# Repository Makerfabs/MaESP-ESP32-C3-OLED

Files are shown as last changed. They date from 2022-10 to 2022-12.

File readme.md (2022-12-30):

# MaESP ESP32 C3 OLED

```c++
/*
Version:		V1.2
Author:			Vincent
Create Date:	2022/9/23
Note:
	2022/12/30	V1.2: Change wiki link
	2022/10/26	V1.1: Add product link and wiki link
*/
```
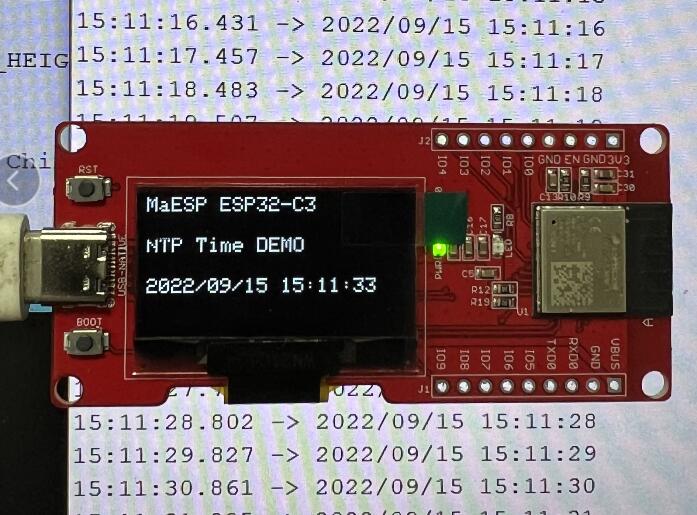
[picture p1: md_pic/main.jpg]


[toc]

# Makerfabs

[Makerfabs home page](https://www.makerfabs.com/)

[Makerfabs Wiki](https://wiki.makerfabs.com/)

# MaESP ESP32 C3 OLED
## Intruduce

Product Link ： [MaESP ESP32-C3 Board with 1.3" OLED](https://www.makerfabs.com/maesp-esp32-c3-board-with-1-3-oled.html)

Wiki Link : [MaESP ESP32-C3 OLED](https://wiki.makerfabs.com/MaESP_ESP32_C3_OLED.html)

MaESP ESP32 C3 OLED equips with ESP32-C3, which is a single-core Wi-Fi and Bluetooth 5 (LE) microcontroller SoC, built around a 32-bit **RISC-V** chip processor with a four-stage pipeline that operates at up to 160 MHz, with 4MB Flash, 400KB SRAM. 

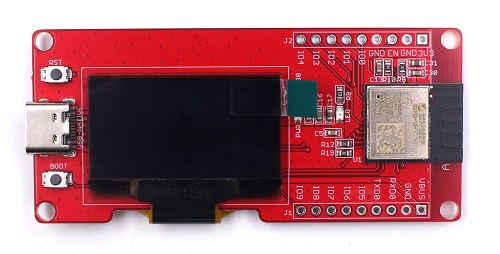
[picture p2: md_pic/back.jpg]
back


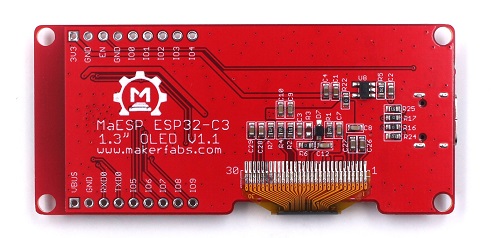
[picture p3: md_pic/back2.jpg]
back2


## Feature

- Controller: ESP32-C3-MINI-1-N4, 4MB Flash, RISCV-32bit, 160MHz, 400KB SRAM, Bluetooth 5
- Wireless: WiFi & Bluetooth 5.0
- Power Supply: USB Type-C 5.0V(4.0V~5.25V)
- Button: Flash button and reset button
- Arduino support: Yes
- Operation temperature: -40℃ to +85℃

# Code

## Complier Option

- Install board : ESP32 .
- Install library : Adafruit_SSD1306, Adafruit_GFX libraries. 
- Use type-c use cable connect USBto PC.
- Upload codes, select "ESP32-C3 DEV Module"
- Some times need press boot button and reset, when COM port not appear.

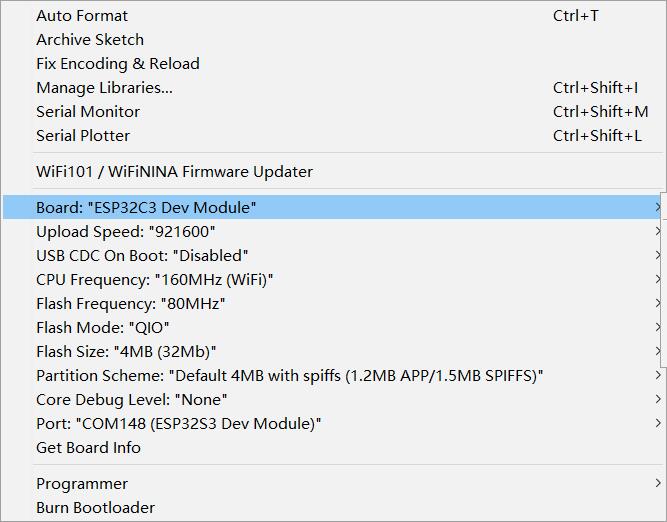
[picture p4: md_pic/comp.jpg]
comp


## Firmware

### CDC_OLED

Different from the commonly used Arduino, the USB interface is directly connected to the ESP32C3, without CP2104 and other chips.

 Therefore, to enable the serial port to send logs normally, use the USBSerial object. This demo show how to use USBSerial and show logo on OLED.

## Example

### NTP_Time

Need chang wifi config .

```c++
#define SSID "Makerfabs"
#define PWD "20160704"
```

Will display NTP time to OLED.

### DHT11_ThingSpeak

Need change ThingSpeak upload url to yourself.

```c++
    String url = "http://api.thingspeak.com/update?api_key=KCAT79TTH52MG7EA&field1=";
    url = url + t + "&field2=" + h;
```

It sends the current temperature and humidity to ThingSpeak when it starts up, and periodically displays the latest temperature and humidity to the OLED.

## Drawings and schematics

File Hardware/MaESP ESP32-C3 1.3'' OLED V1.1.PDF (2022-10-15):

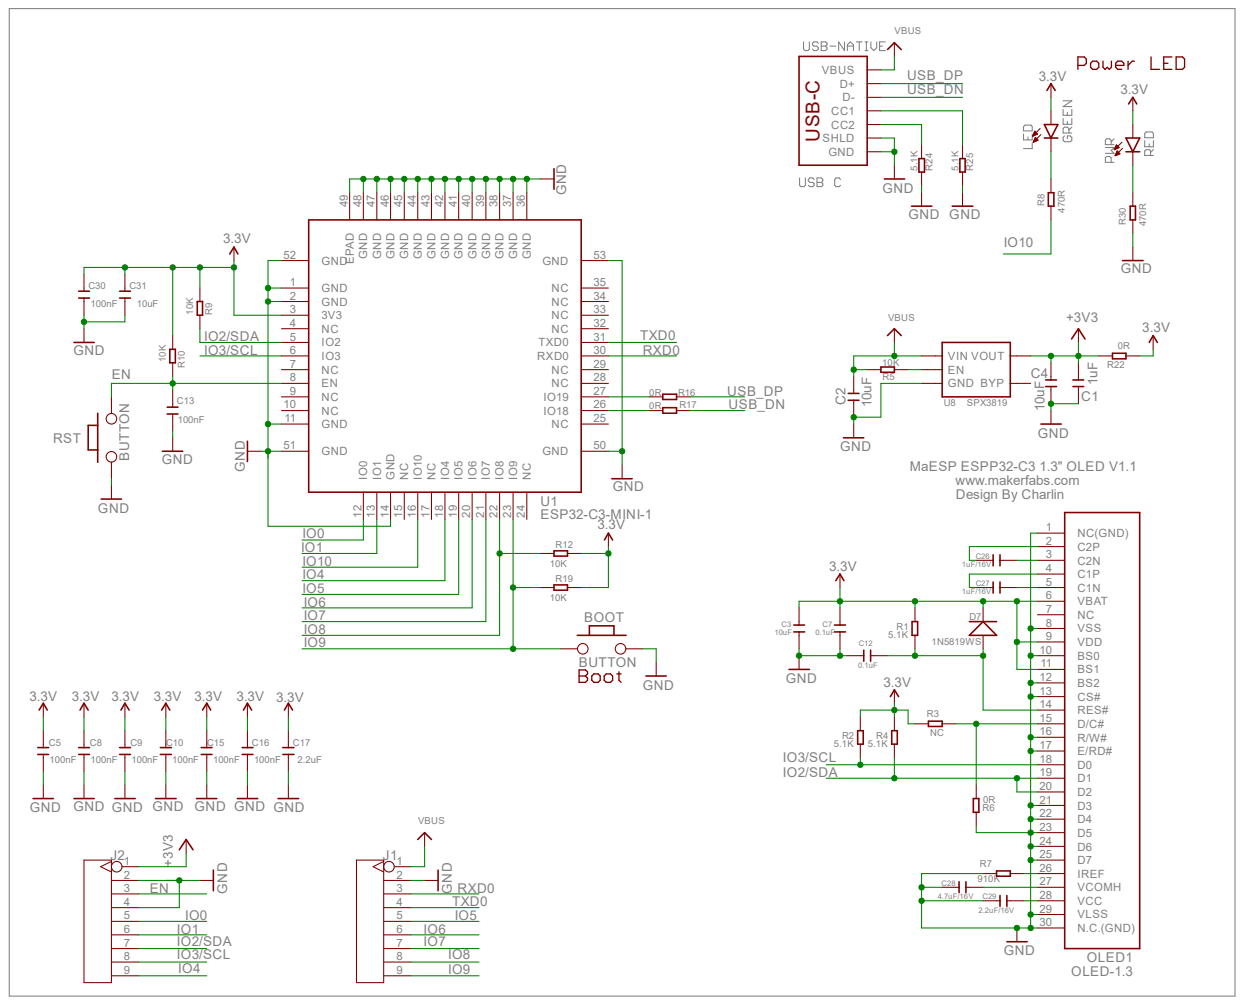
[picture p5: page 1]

NC 7 VSS 8 VDD 9

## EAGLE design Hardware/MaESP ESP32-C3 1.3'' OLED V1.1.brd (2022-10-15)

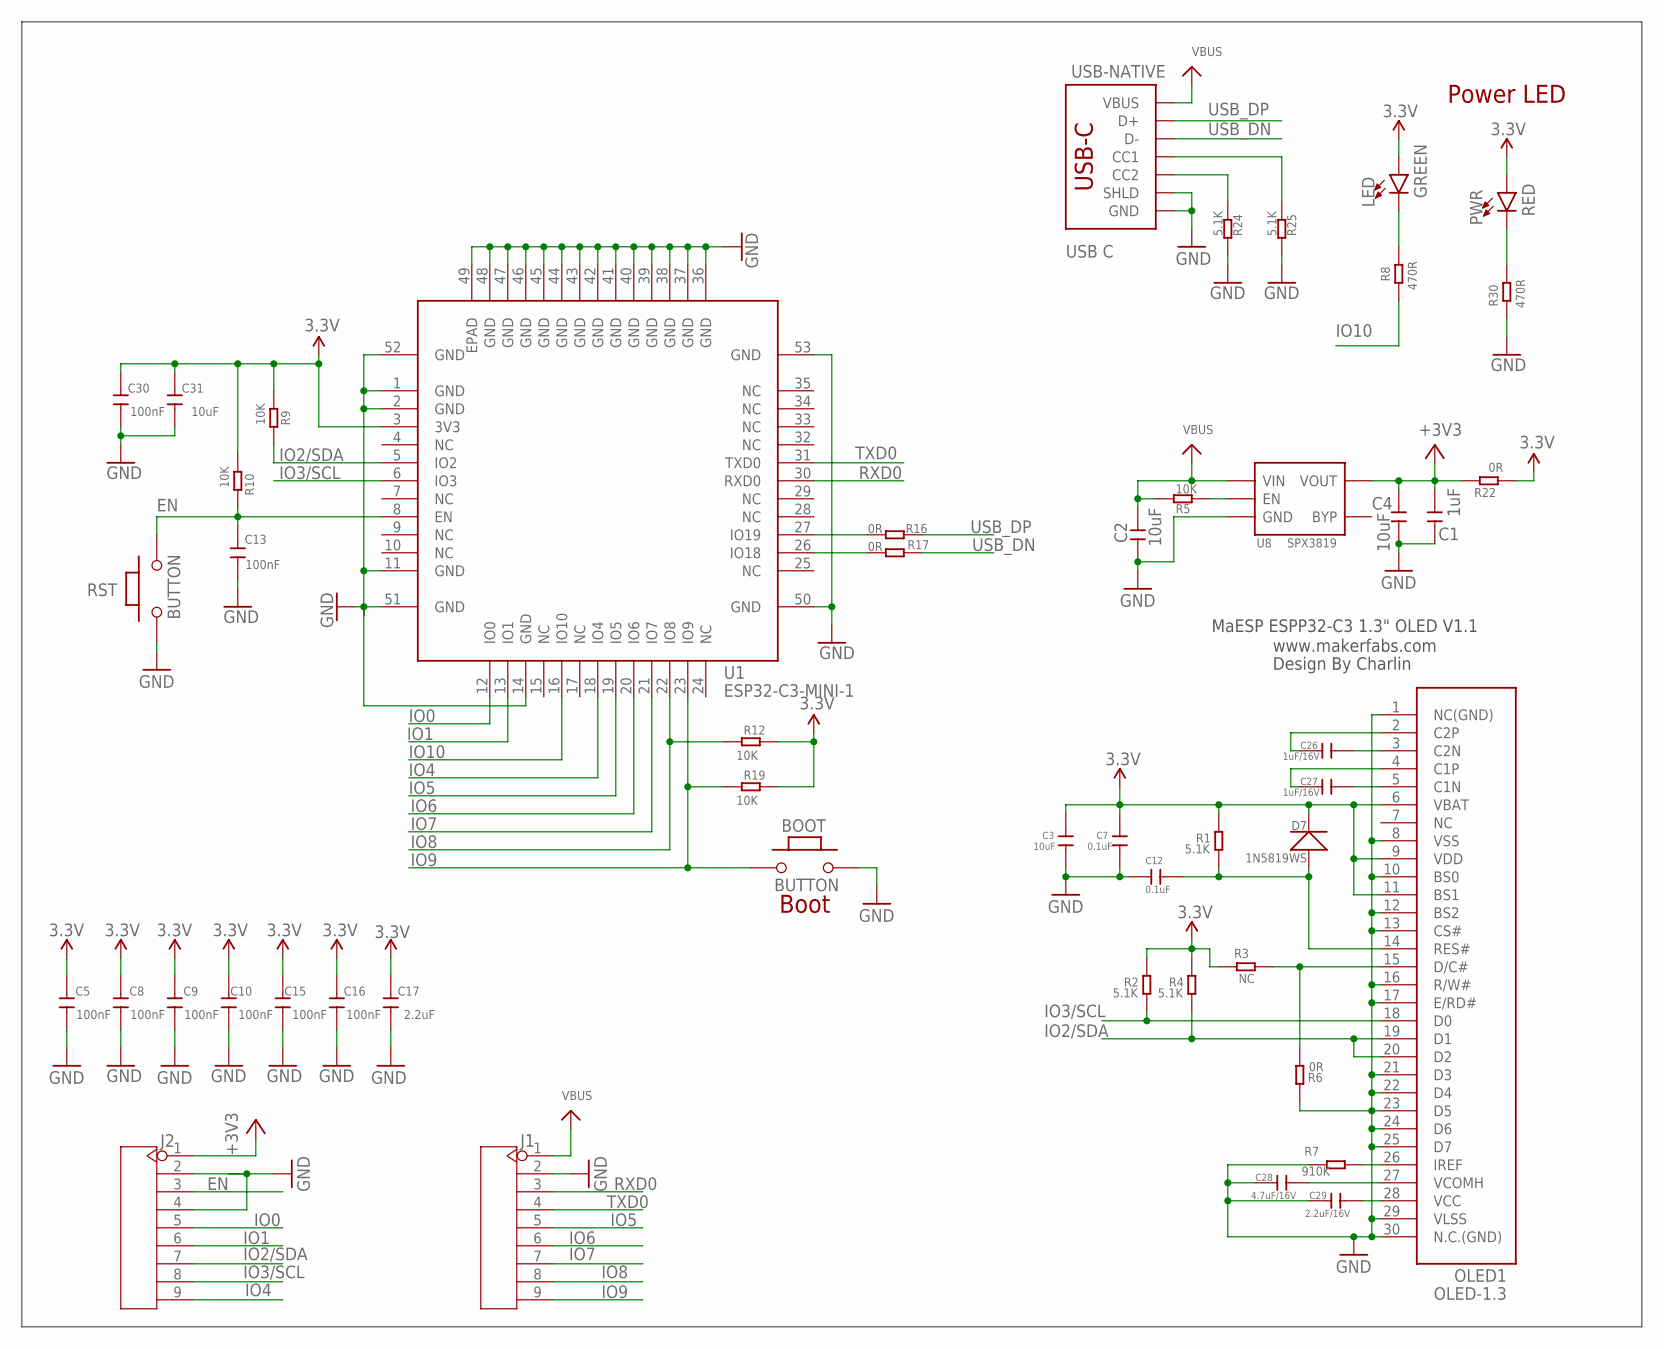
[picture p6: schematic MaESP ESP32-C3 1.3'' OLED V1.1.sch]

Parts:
BOOT: BUTTON; 157SW
C1: 1uF; C0603
C2, C3, C4, C31: 10uF; C0603
C5, C8, C9, C10, C13, C15, C16, C30: 100nF; C0603
C7, C12: 0.1uF; C0603
C17: 2.2uF; C0603
C26, C27: 1uF/16V; C0603
C28: 4.7uF/16V; C0603
C29: 2.2uF/16V; C0603
D7: 1N5819WS; SOD323
J1, J2: HEADER-9P-2.54; 9P-2.54
LED: GREEN; LED-0603
OLED1: OLED-1.3
PWR: RED; LED-0603
R1, R2, R4, R24, R25: 5.1K; R0603
R3: NC; R0603
R5, R9, R10, R12, R19: 10K; R0603
R6, R16, R17, R22: 0R; R0603
R7: 910K; R0603
R8, R30: 470R; R0603
RST: BUTTON; 157SW
U1: ESP32-C3-MINI-1
U8: SPX3819; SOT23-5
USB-NATIVE: USB C; USB-C-16P-4LAYER-ISOLATED

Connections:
3.3V: C3.1, C5.2, C7.1, C8.2, C9.2, C10.2, C15.2, C16.2, C17.2, C30.2, C31.2, D7.-, LED.A, OLED1.6 (VBAT), OLED1.9 (VDD), OLED1.11 (BS1), PWR.A, R1.2, R2.2, R3.2, R4.2, R9.1, R10.1, R12.2, R19.2, R22.1, U1.3 (3V3)
3V3_EN: R5.2, U8.3 (EN)
+3V3: C1.2, C4.2, J2.1, R22.2, U8.5 (VOUT)
EN: C13.2, J2.3, R10.2, RST.2, U1.8 (EN)
GND: BOOT.2, C1.1, C2.1, C3.2, C4.1, C5.1, C7.2, C8.1, C9.1, C10.1, C12.1, C13.1, C15.1, C16.1, C17.1, C28.1, C29.1, C30.1, C31.1, J1.2, J2.2, J2.4, OLED1.1 (NC(GND)), OLED1.8 (VSS), OLED1.10 (BS0), OLED1.12 (BS2), OLED1.13 (CS#), OLED1.16 (R/W#), OLED1.17 (E/RD#), OLED1.21 (D3), OLED1.22 (D4), OLED1.23 (D5), OLED1.24 (D6), OLED1.25 (D7), OLED1.29 (VLSS), OLED1.30 (N.C.(GND)), R6.2, R7.2, R24.1, R25.1, R30.2, RST.1, U1.1 (GND), U1.2 (GND), U1.11 (GND), U1.14 (GND), U1.36 (GND), U1.37 (GND), U1.38 (GND), U1.39 (GND), U1.40 (GND), U1.41 (GND), U1.42 (GND), U1.43 (GND), U1.44 (GND), U1.45 (GND), U1.46 (GND), U1.47 (GND), U1.48 (GND), U1.49 (EPAD), U1.50 (GND), U1.51 (GND), U1.52 (GND), U1.53 (GND), U8.2 (GND), USB-NATIVE.GND, USB-NATIVE.GND2 (GND), USB-NATIVE.SHLD1 (SHLD), USB-NATIVE.SHLD2 (SHLD), USB-NATIVE.SHLD3 (SHLD), USB-NATIVE.SHLD4 (SHLD), USB-NATIVE.SHLD5 (SHLD), USB-NATIVE.SHLD6 (SHLD), USB-NATIVE.SHLD7 (SHLD), USB-NATIVE.SHLD8 (SHLD)
IO0: J2.5, U1.12 (IO0)
IO1: J2.6, U1.13 (IO1)
IO2/SDA: J2.7, OLED1.19 (D1), OLED1.20 (D2), R4.1, R9.2, U1.5 (IO2)
IO3/SCL: J2.8, OLED1.18 (D0), R2.1, U1.6 (IO3)
IO4: J2.9, U1.18 (IO4)
IO5: J1.5, U1.19 (IO5)
IO6: J1.6, U1.20 (IO6)
IO7: J1.7, U1.21 (IO7)
IO8: J1.8, R12.1, U1.22 (IO8)
IO9: BOOT.1, J1.9, R19.1, U1.23 (IO9)
IO10: R8.2, U1.16 (IO10)
unnamed: LED.C, R8.1
unnamed: OLED1.15 (D/C#), R3.1, R6.1
unnamed: C28.2, OLED1.27 (VCOMH)
unnamed: PWR.C, R30.1
unnamed: C29.2, OLED1.28 (VCC)
unnamed: OLED1.26 (IREF), R7.1
unnamed: C26.2, OLED1.3 (C2N)
unnamed: R25.2, USB-NATIVE.A5 (CC1)
unnamed: R24.2, USB-NATIVE.B5 (CC2)
unnamed: C26.1, OLED1.2 (C2P)
unnamed: C27.1, OLED1.4 (C1P)
unnamed: C27.2, OLED1.5 (C1N)
unnamed: R17.1, U1.26 (IO18)
unnamed: R16.1, U1.27 (IO19)
unnamed: C12.2, D7.+, OLED1.14 (RES#), R1.1
RXD0: J1.3, U1.30 (RXD0)
TXD0: J1.4, U1.31 (TXD0)
USB_DN: R17.2, USB-NATIVE.A7 (D-), USB-NATIVE.B7 (D-)
USB_DP: R16.2, USB-NATIVE.A6 (D+), USB-NATIVE.B6 (D+)
VBUS: C2.2, J1.1, R5.1, U8.1 (VIN), USB-NATIVE.VBUS1 (VBUS), USB-NATIVE.VBUS2 (VBUS)

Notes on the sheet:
MaESP ESPP32-C3 1.3" OLED V1.1
www.makerfabs.com
Boot
Power LED
Design By Charlin

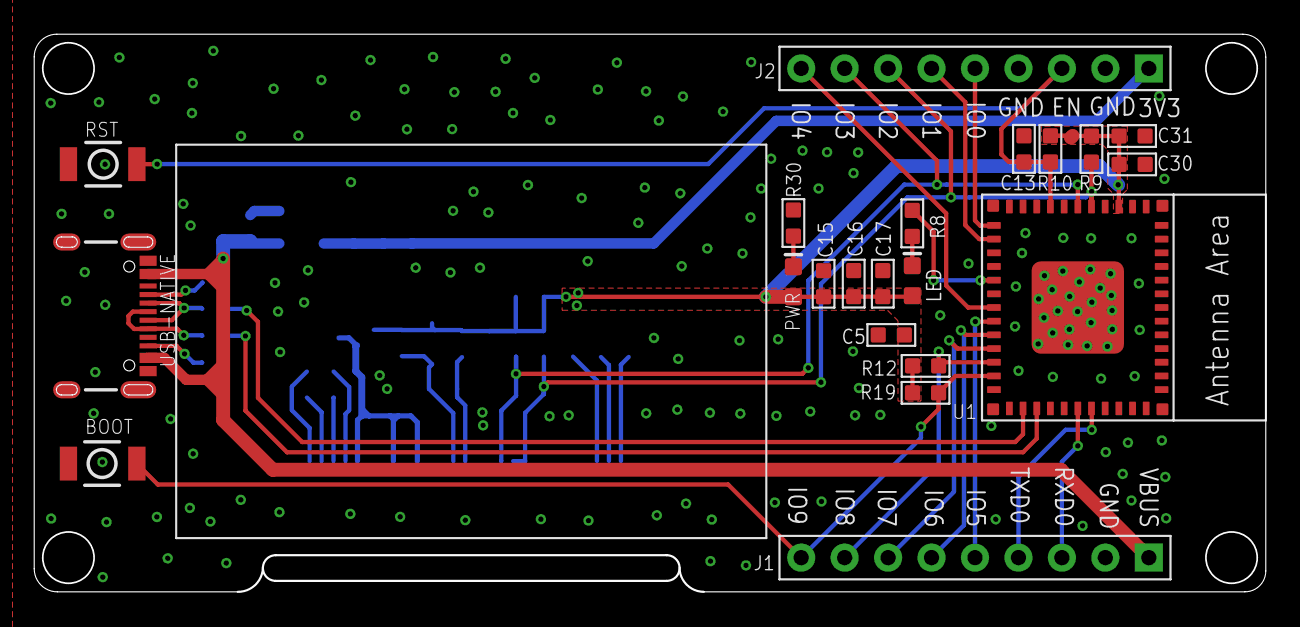
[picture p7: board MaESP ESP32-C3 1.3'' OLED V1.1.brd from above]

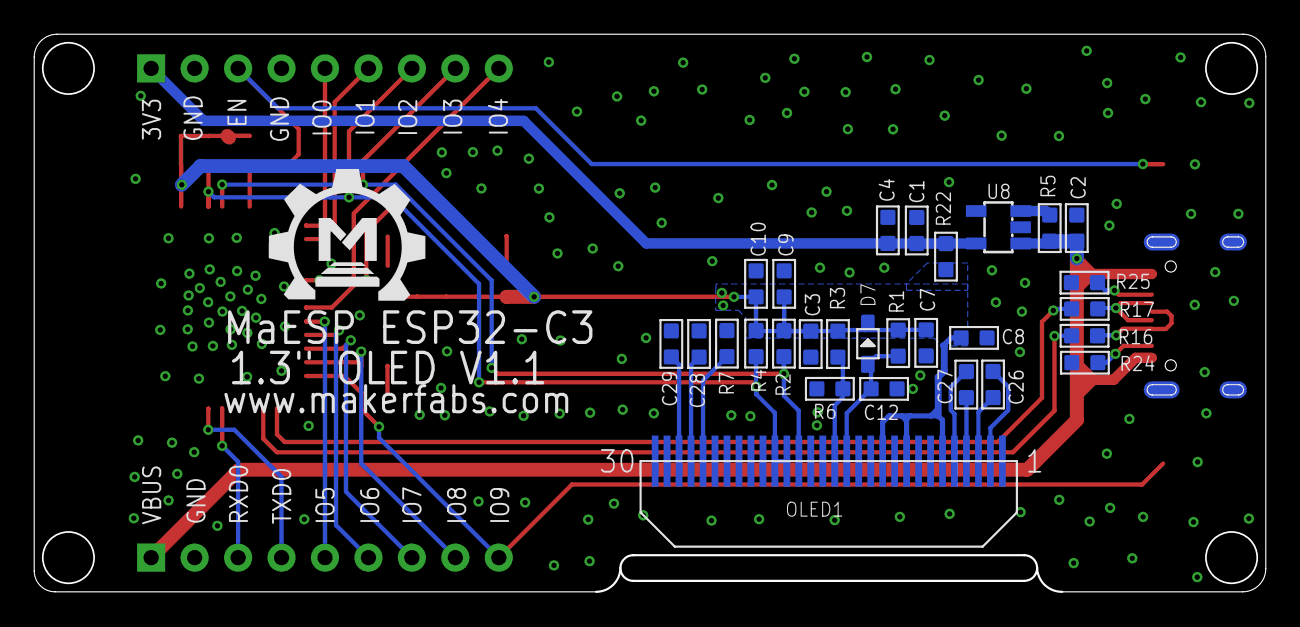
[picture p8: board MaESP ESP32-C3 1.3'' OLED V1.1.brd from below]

Board: 2 copper layers, 72.0 x 32.6 mm, 50 parts (28 on the bottom side), 36 nets.

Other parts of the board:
U$1: MAKERFABS_0.3

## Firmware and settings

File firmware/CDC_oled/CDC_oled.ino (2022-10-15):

#include <Adafruit_GFX.h>
#include <Adafruit_SSD1306.h>

// SSD1306
#define C3_SDA 2
#define C3_SCL 3
#define SCREEN_WIDTH 128 // OLED display width, in pixels
#define SCREEN_HEIGHT 64 // OLED display height, in pixels
#define OLED_RESET -1    // Reset pin # (or -1 if sharing Arduino reset pin)

Adafruit_SSD1306 display(SCREEN_WIDTH, SCREEN_HEIGHT, &Wire, OLED_RESET);

void logoshow(void);

void setup()
{
    USBSerial.begin(115200);
    USBSerial.println("MaESP C3 begin V1.0");

    // LCD
    Wire.begin(C3_SDA, C3_SCL);
    // SSD1306_SWITCHCAPVCC = generate display voltage from 3.3V internally
    if (!display.begin(SSD1306_SWITCHCAPVCC, 0x3C))
    { // Address 0x3C for 128x32
        Serial.println(F("SSD1306 allocation failed"));
        for (;;)
            ; // Don't proceed, loop forever
    }
    logoshow();
}

int loop_count = 0;

void loop()
{
    USBSerial.printf("USBSerial %d\n", loop_count);
    loop_count++;
    delay(1000);
     logoshow();
    display.display();
}

void logoshow(void)
{
  display.clearDisplay();
  display.setTextSize(1);              // Normal 1:1 pixel scale
  display.setTextColor(WHITE);
  display.setTextSize(1.5);
  display.setCursor(0, 0);
  display.print(F("Hello! Makers"));   //increase F( ) in onder to put the constant in RAM to avoid the ROW not enough use in the AVR platfrom. variable  didn't use this way.
  display.setCursor(0, 20);
  display.print(F("time: "));
  display.print(millis() / 1000);
  display.print(F(" s"));
  display.setCursor(0, 40);
  display.print(F("Author: "));
  display.print(F("Makerfabs"));
      display.display();
}

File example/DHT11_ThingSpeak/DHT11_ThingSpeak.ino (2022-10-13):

#include <Adafruit_GFX.h>
#include <Adafruit_SSD1306.h>
#include <WiFi.h>
#include <HTTPClient.h>
#include "DHT.h"

#define SSID "Makerfabs"
#define PWD "20160704"

// SSD1306
#define C3_SDA 2
#define C3_SCL 3
#define SCREEN_WIDTH 128 // OLED display width, in pixels
#define SCREEN_HEIGHT 64 // OLED display height, in pixels
#define OLED_RESET -1    // Reset pin # (or -1 if sharing Arduino reset pin)

Adafruit_SSD1306 display(SCREEN_WIDTH, SCREEN_HEIGHT, &Wire, OLED_RESET);

#define DHTPIN 4      // Digital pin connected to the DHT sensor
#define DHTTYPE DHT11 // DHT11
DHT dht(DHTPIN, DHTTYPE);

String dht_str = "";
float h = 0.0;
float t = 0.0;

void setup()
{
    USBSerial.begin(115200);
    USBSerial.println("MaESP C3 begin");

    // LCD
    Wire.begin(C3_SDA, C3_SCL);
    // SSD1306_SWITCHCAPVCC = generate display voltage from 3.3V internally
    if (!display.begin(SSD1306_SWITCHCAPVCC, 0x3C))
    { // Address 0x3C for 128x32
        USBSerial.println(F("SSD1306 allocation failed"));
        for (;;)
            ; // Don't proceed, loop forever
    }

    dht.begin();

    WiFi.begin(SSID, PWD);
    int connect_count = 0;
    while (WiFi.status() != WL_CONNECTED)
    {
        delay(500);
        USBSerial.print(".");
        connect_count++;
        if (connect_count > 20)
        {
            USBSerial.println("Wifi time out");
            break;
        }
    }

    logoshow();
    delay(2000);
    while (1)
    {
        if (get_dht() != 0)
        {
            weather_request();
            delay(3000);
            break;
        }
        delay(3000);
    }
}

long runtime = 0;

void loop()
{

    display.setCursor(0, 40);            // Start at top-left corner
    display.setTextColor(SSD1306_BLACK); // Draw white text
    display.println(dht_str);
    get_dht();

    display.setCursor(0, 40);            // Start at top-left corner
    display.setTextColor(SSD1306_WHITE); // Draw white text
    display.println(dht_str);
    display.display();

    delay(2000);
}

void logoshow(void)
{
    display.clearDisplay();

    display.setTextSize(1);              // Normal 1:1 pixel scale
    display.setTextColor(SSD1306_WHITE); // Draw white text
    display.setCursor(0, 0);             // Start at top-left corner
    display.println(F("MaESP ESP32-C3"));
    display.setCursor(0, 20); // Start at top-left corner
    display.println(F("DHT11 to ThingSpeak"));
    display.display();
    delay(3000);
}

int get_dht()
{

    h = dht.readHumidity();
    t = dht.readTemperature();
    // Check if any reads failed and exit early (to try again).
    if (isnan(h) || isnan(t))
    {
        USBSerial.println(F("Failed to read from DHT sensor!"));
        return 0;
    }

    dht_str = "";
    dht_str = dht_str + "TEMP:" + (int)t + " C HUMI:" + (int)h + " %";
    USBSerial.println(dht_str);

    return 1;
}

void weather_request()
{
    HTTPClient http;
    String url = "http://api.thingspeak.com/update?api_key=KCAT79TTH52MG7EA&field1=";
    url = url + t + "&field2=" + h;
    http.begin(url);
    http.GET();
    http.end();
}

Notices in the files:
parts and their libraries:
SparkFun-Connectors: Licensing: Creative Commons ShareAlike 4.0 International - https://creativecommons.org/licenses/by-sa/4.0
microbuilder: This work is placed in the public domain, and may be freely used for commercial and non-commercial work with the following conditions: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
